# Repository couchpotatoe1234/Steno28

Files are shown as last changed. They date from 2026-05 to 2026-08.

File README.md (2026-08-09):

# Steno28
A simple hand soldered stenography keyboard with 28 keys. I made this keyboard because I find Stenography keboards interesting and I decided to try making one myself. The PCB is relatively simple, being designed in KiCAD and using the Raspberry Pi Pico RP2040 to connect to the computer. Screenshot 2026-05-06 at 7 28 45 AM I didn't bother attempting onboard programming, because that would require attempting to code every single chord I would ever want to type. Rather, I will be using Plover (https://opensteno.org/plover/) that will translate the chords into words. The case is pretty simple, with the PCB just directly screwed on to the case, making it seem as if theres almost no case. It is not supposed to have a plate and is supposed to have a sort of "open-air" PCB. Its really just there to protect the wiring. It will look something like this (sry about the badly rendered keycaps...) Screenshot 2026-07-13 at 7 17 56 AM I designed the case in Onshape:https://cad.onshape.com/documents/53637eff7d4d43c451aa77bb/w/a1ff151550c121314276b672/e/7c0bff2a6c8d979b5125e58d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

Heres the BOM:

| Name | Description | Quantity | Total Cost (USD) | Link | Distributor |
|---|---|---|---|---|---|
| PCB | Main Component | 1 | 11-12 | https://jlcpcb.com | JLCPCB |
| Gateron Milky Yellow switches | Key switches for the keyboard | 3 | 5-7 | https://www.aliexpress.us/item/3256808155159388.html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 | Aliexpress  |
| M3 screws, 25mm long | to connect the PCB to the case | 2 | 2-3 | https://www.aliexpress.us/item/3256807894724568.html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 | Aliexpress  |
| 40 pin header | to connect the pi to the PCB. will be split in half. | 1 | 2-5 | https://www.aliexpress.us/item/3256809184452517.html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 | Aliexpress  |
| Raspberry Pi Pico RP2040 | the main microcontroller | 1 | 2-4 | hhttps://www.aliexpress.us/item/3256806652932348.html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 | Aliexpress  |
| 1N4148 diodes | diodes for the matrix | 28 | 1-3 | https://www.aliexpress.us/item/3256809192784213.html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 | Aliexpress  |

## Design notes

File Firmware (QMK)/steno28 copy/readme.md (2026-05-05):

# steno28

steno28

*A short description of the keyboard/project*

* Keyboard Maintainer: [couchpotatoe1234](https://github.com/couchpotatoe1234)
* Hardware Supported: *The PCBs, controllers supported*
* Hardware Availability: *Links to where you can find this hardware*

Make example for this keyboard (after setting up your build environment):

    make steno28:default

Flashing example for this keyboard:

    make steno28:default:flash

See the [build environment setup](https://docs.qmk.fm/#/getting_started_build_tools) and the [make instructions](https://docs.qmk.fm/#/getting_started_make_guide) for more information. Brand new to QMK? Start with our [Complete Newbs Guide](https://docs.qmk.fm/#/newbs).

## Bootloader

Enter the bootloader in 3 ways:

* **Bootmagic reset**: Hold down the key at (0,0) in the matrix (usually the top left key or Escape) and plug in the keyboard
* **Physical reset button**: Briefly press the button on the back of the PCB - some may have pads you must short instead
* **Keycode in layout**: Press the key mapped to `QK_BOOT` if it is available

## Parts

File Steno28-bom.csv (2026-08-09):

Name | Description | Quantity | Total Cost (USD) | Link | Distributor
PCB | Main Component | 1 | 11-12 | https://jlcpcb.com | JLCPCB
Gateron Milky Yellow switches | Key switches for the keyboard | 3 | 5-7 | https://www.aliexpress.us/item/3256808155159388.html?curPageLogUid=SlbQkXYMbyc8 | Aliexpress
M3 screws, 25mm long | to connect the PCB to the case | 2 | 2-3 | https://www.aliexpress.us/item/3256807894724568.html?curPageLogUid=Axerb0q0V5Js | Aliexpress
40 pin header | to connect the pi to the PCB. will be split in half. | 1 | 2-5 | https://www.aliexpress.us/item/3256809184452517.html | Aliexpress
Raspberry Pi Pico RP2040 | the main microcontroller | 1 | 2-4 | hhttps://www.aliexpress.us/item/3256806652932348.html?curPageLogUid=E4APFhff29iy | Aliexpress
1N4148 diodes | diodes for the matrix | 28 | 1-3 | https://www.aliexpress.us/item/3256809192784213.html?curPageLogUid=z294DkysUBGn | Aliexpress

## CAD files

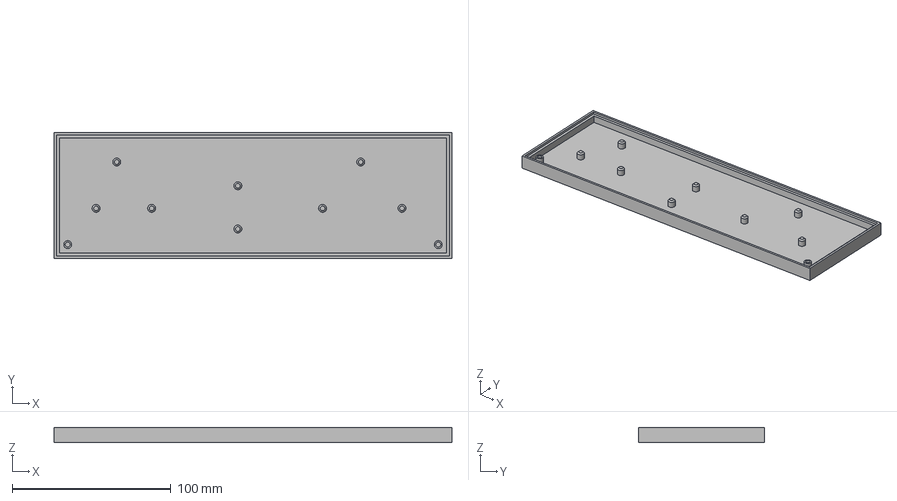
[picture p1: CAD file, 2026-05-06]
Case/Steno28PCB parts - Part 5.step
250.6 x 79.2 x 9.60 mm

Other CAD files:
Case/Steno28PCB parts - Part 5.stl

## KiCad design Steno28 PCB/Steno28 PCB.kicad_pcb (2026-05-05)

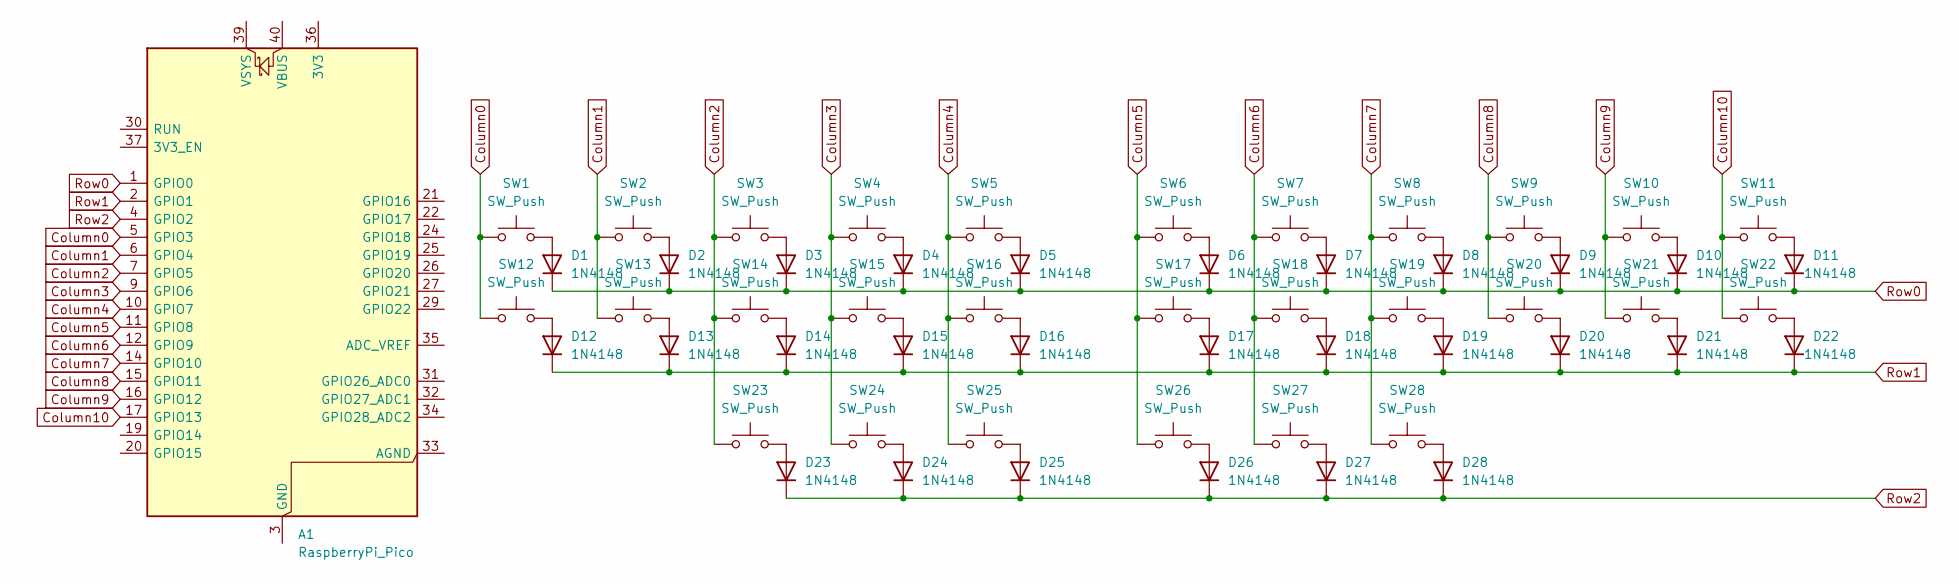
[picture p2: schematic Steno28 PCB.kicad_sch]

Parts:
A1: RaspberryPi_Pico; RaspberryPi_Pico_Common_Unspecified
D1, D2, D3, D4, D5, D6, D7, D8, D9, D10, D11, D12, D13, D14, D15, D16, D17, D18, D19, D20, D21, D22, D23, D24, D25, D26, D27, D28: 1N4148; D_DO-35_SOD27_P7.62mm_Horizontal
SW1, SW2, SW3, SW4, SW5, SW6, SW7, SW8, SW9, SW10, SW11, SW12, SW13, SW14, SW15, SW16, SW17, SW18, SW19, SW20, SW21, SW22, SW23, SW24, SW25, SW26, SW27, SW28: SW_Push; SW_Cherry_MX_1.00u_PCB

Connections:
Column0: A1.5 (GPIO3), SW1.1, SW12.1
Column1: A1.6 (GPIO4), SW2.1, SW13.1
Column2: A1.7 (GPIO5), SW3.1, SW14.1, SW23.1
Column3: A1.9 (GPIO6), SW4.1, SW15.1, SW24.1
Column4: A1.10 (GPIO7), SW5.1, SW16.1, SW25.1
Column5: A1.11 (GPIO8), SW6.1, SW17.1, SW26.1
Column6: A1.12 (GPIO9), SW7.1, SW18.1, SW27.1
Column7: A1.14 (GPIO10), SW8.1, SW19.1, SW28.1
Column8: A1.15 (GPIO11), SW9.1, SW20.1
Column9: A1.16 (GPIO12), SW10.1, SW21.1
Column10: A1.17 (GPIO13), SW11.1, SW22.1
unnamed: A1.3 (GND), A1.8 (GND), A1.13 (GND), A1.18 (GND), A1.23 (GND), A1.28 (GND), A1.38 (GND)
unnamed: D1.2 (A), SW1.2
unnamed: D2.2 (A), SW2.2
unnamed: D3.2 (A), SW3.2
unnamed: D4.2 (A), SW4.2
unnamed: D5.2 (A), SW5.2
unnamed: D6.2 (A), SW6.2
unnamed: D7.2 (A), SW7.2
unnamed: D8.2 (A), SW8.2
unnamed: D9.2 (A), SW9.2
unnamed: D10.2 (A), SW10.2
unnamed: D11.2 (A), SW11.2
unnamed: D12.2 (A), SW12.2
unnamed: D13.2 (A), SW13.2
unnamed: D14.2 (A), SW14.2
unnamed: D15.2 (A), SW15.2
unnamed: D16.2 (A), SW16.2
unnamed: D17.2 (A), SW17.2
unnamed: D18.2 (A), SW18.2
unnamed: D19.2 (A), SW19.2
unnamed: D20.2 (A), SW20.2
unnamed: D21.2 (A), SW21.2
unnamed: D22.2 (A), SW22.2
unnamed: D23.2 (A), SW23.2
unnamed: D24.2 (A), SW24.2
unnamed: D25.2 (A), SW25.2
unnamed: D26.2 (A), SW26.2
unnamed: D27.2 (A), SW27.2
unnamed: D28.2 (A), SW28.2
Row0: A1.1 (GPIO0), D1.1 (K), D2.1 (K), D3.1 (K), D4.1 (K), D5.1 (K), D6.1 (K), D7.1 (K), D8.1 (K), D9.1 (K), D10.1 (K), D11.1 (K)
Row1: A1.2 (GPIO1), D12.1 (K), D13.1 (K), D14.1 (K), D15.1 (K), D16.1 (K), D17.1 (K), D18.1 (K), D19.1 (K), D20.1 (K), D21.1 (K), D22.1 (K)
Row2: A1.4 (GPIO2), D23.1 (K), D24.1 (K), D25.1 (K), D26.1 (K), D27.1 (K), D28.1 (K)

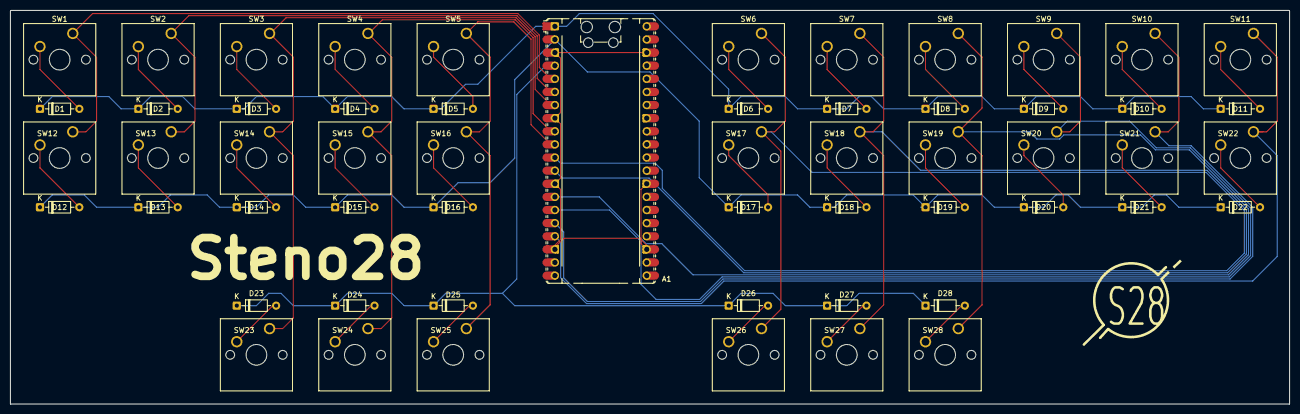
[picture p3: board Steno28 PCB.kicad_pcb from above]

Board: 2 copper layers, 247.6 x 76.2 mm, 57 parts (0 on the bottom side), 43 nets.

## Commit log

2026-05-05 firmware, PCB, & Gerbers
    [Steno28 PCB.kicad_pcb, Steno28 PCB.kicad_sch]
2026-05-06 BOM & README
    [Steno28-bom.csv]
2026-07-13 stl and readme
    [Steno28PCB parts - Part 5.stl]
2026-07-13 Update README to specify hand soldered keyboard
2026-08-09 updating BOM
    [Steno28-bom.csv]
2026-08-09 readme BOM update
2026-08-10 overall model added in cad folder
